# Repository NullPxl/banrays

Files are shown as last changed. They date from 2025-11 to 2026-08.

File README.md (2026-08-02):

# Ban-Rays
**Glasses to detect smart-glasses that have cameras**

I'm experimenting with 2 main approaches:
* [Optics](#optics): classify the camera using light reflections.
* [Networking](#networking): bluetooth and wi-fi analysis.

So far fingerprinting specific devices based on bluetooth (BLE) is looking like easiest and most reliable approach. The picture below is the first version, which plays the legend of zelda 'secret found' jingle when it detects a BLE advertisement from Meta Raybans.

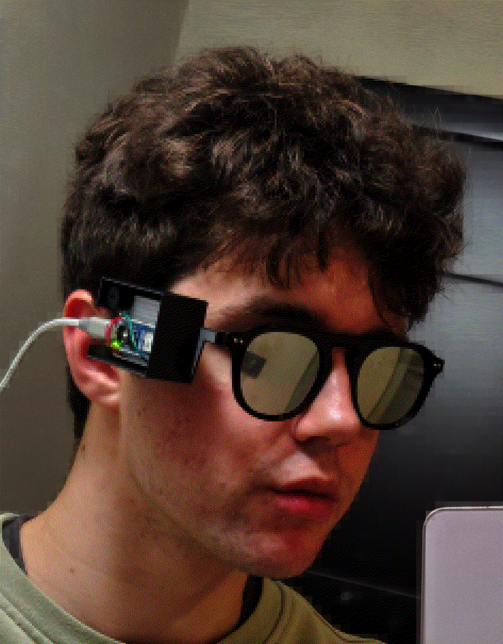
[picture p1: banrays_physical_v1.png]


I'm essentially treating this README like a logbook, so it will have my current approaches/ideas.

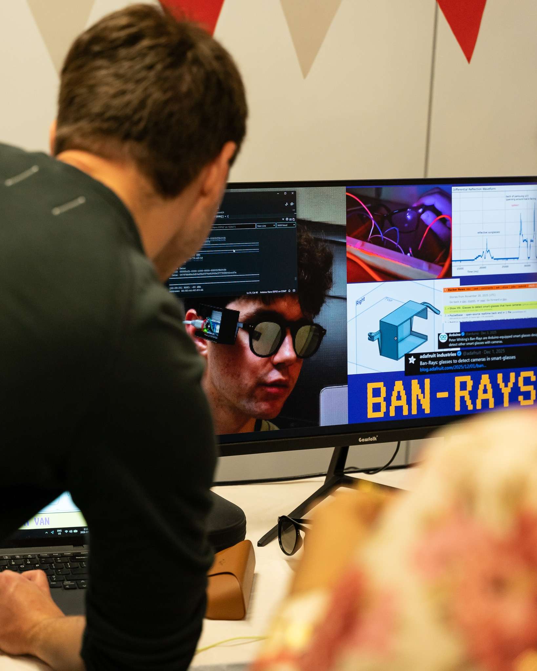
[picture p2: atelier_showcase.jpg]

Back when I released this initial research around November 2025 it hit top of hackernews and got some nice tweets! I also got to show it to some cool people at Atelier Showcase.

## Optics

By sending IR at camera lenses, we can take advantage of the fact that the CMOS sensor in a camera reflects light directly back at the source (called 'retro-reflectivity' / 'cat-eye effect') to identify cameras.

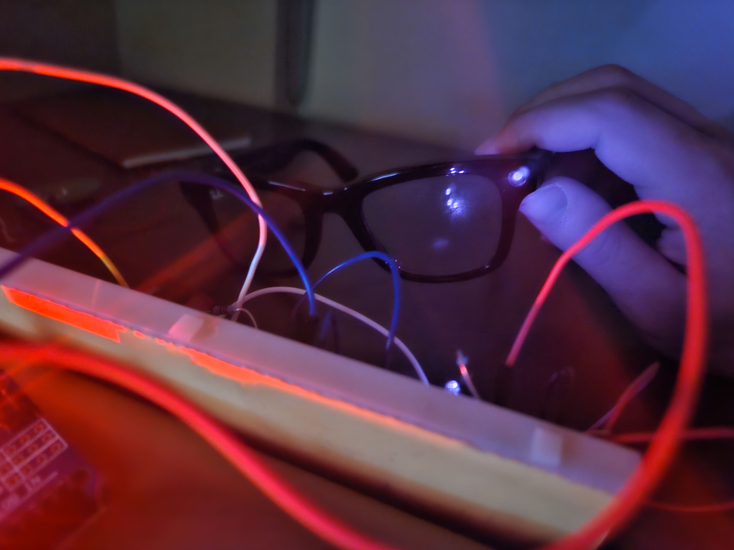
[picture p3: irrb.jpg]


This isn't exactly a new idea. Some researchers in 2005 used this property to create 'capture-resistant environments' when smartphones with cameras were gaining popularity. 
* https://homes.cs.washington.edu/~shwetak/papers/cre.pdf

There's even some recent research (2024) that figured out how to classify individual cameras based on their retro-reflections.
* https://opg.optica.org/oe/fulltext.cfm?uri=oe-32-8-13836

Now we have a similar situation to those 2005 researchers on our hands, where smart glasses with hidden cameras seem to be getting more popular. So I want to create a pair of glasses to identify these. Unfortunately, from what I can tell most of the existing research in this space records data with a camera and then uses ML, a ton of controlled angles, etc. to differentiate between normal reflective surfaces and cameras. 

I would feel pretty silly if my solution uses its own camera. So I'll be avoiding that. Instead I think it's likely I'll have to rely on being consistent with my 'sweeps', and creating a good classifier based on signal data. For example you can see here that the back camera on my smartphone seems to produce quick and large spikes, while the glossy screen creates a more prolonged wave. 

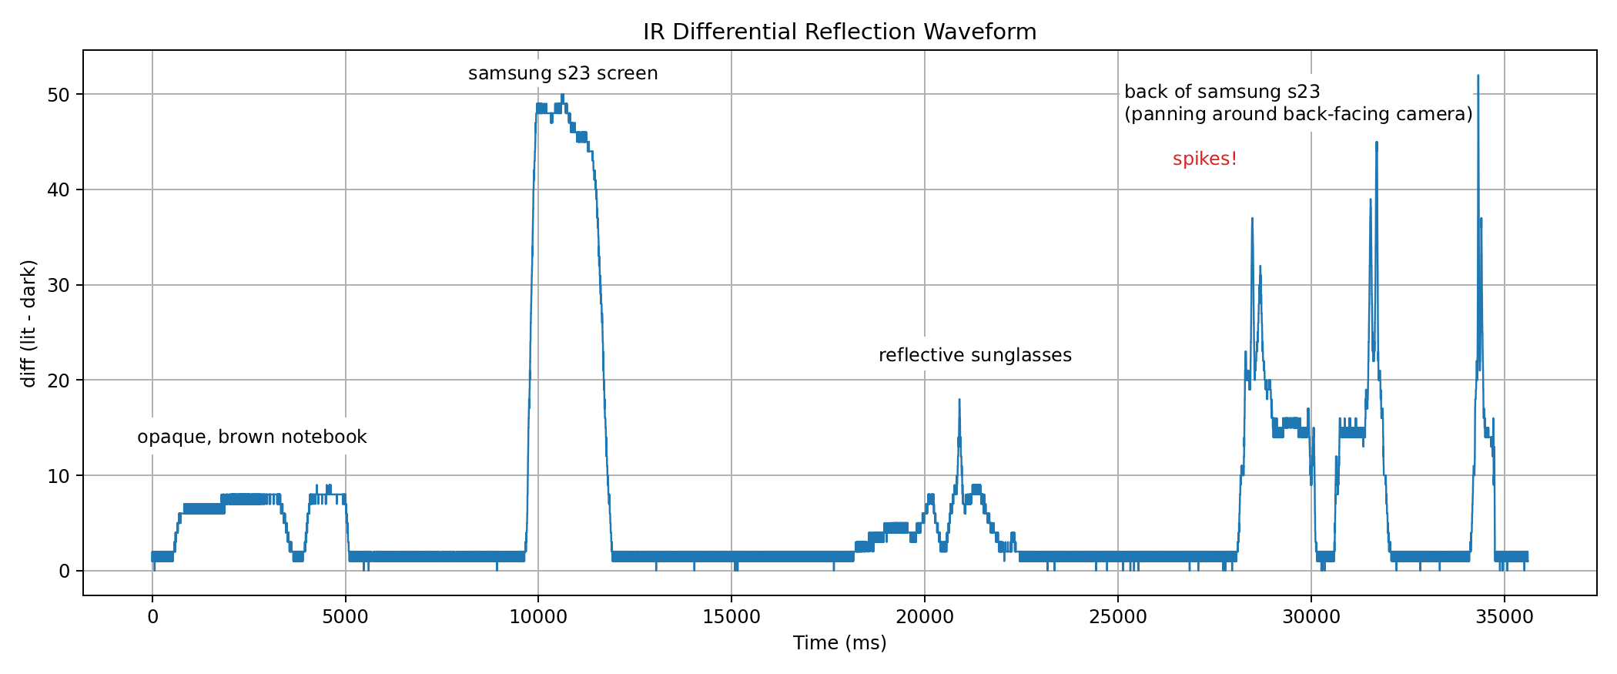
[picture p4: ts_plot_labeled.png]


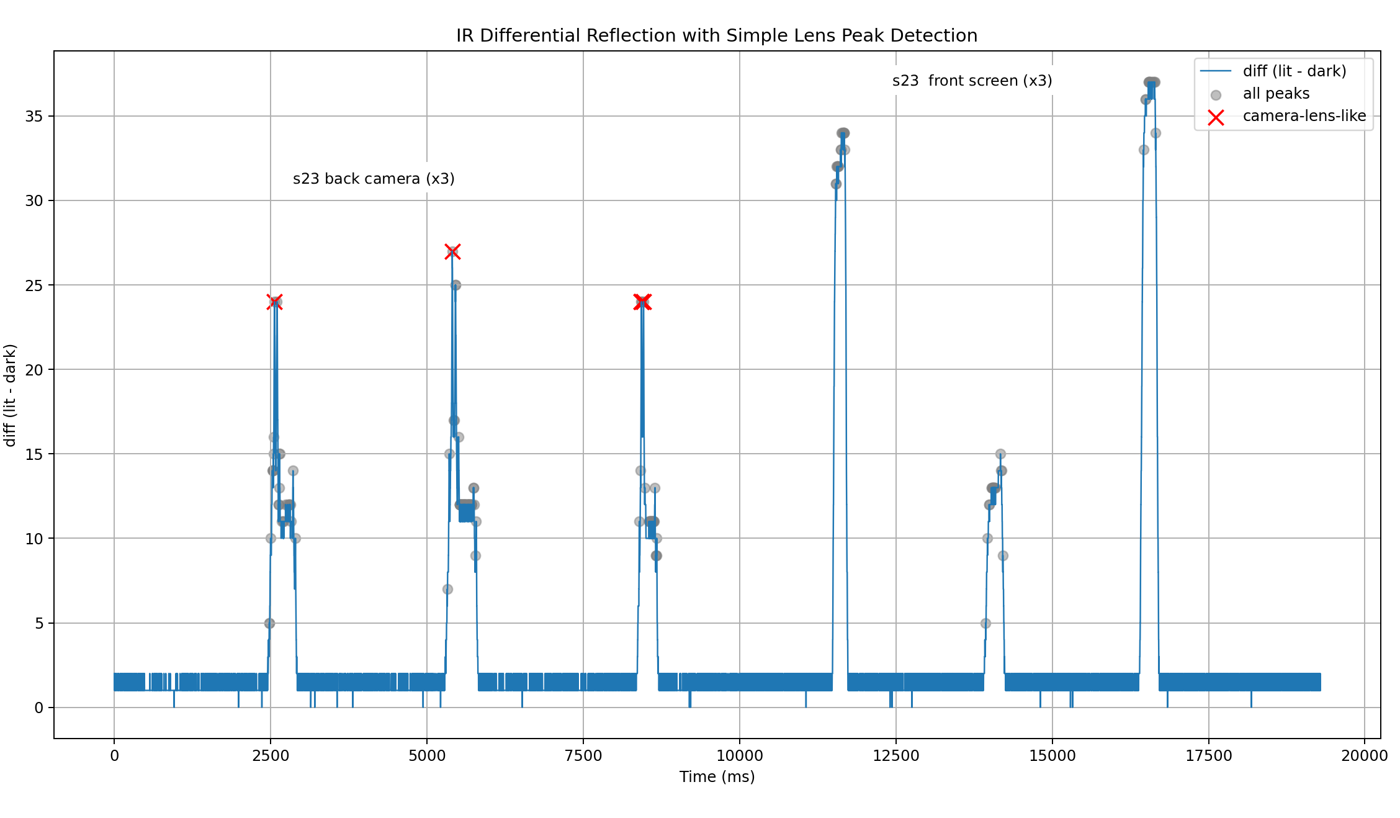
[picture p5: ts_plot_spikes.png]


After getting to test some Meta Raybans, I found that this setup is not going to be sufficient. Here's a test of some sweeps of the camera-area + the same area when the lens is covered. You can see the waveform is similar to what I saw in the earlier test (short spike for camera, wider otherwise), but it's wildly inconsistent and the strength of the signal is very weak. This was from about 4 inches away from the LEDs. I didn't notice much difference when swapping between 940nm and 850nm LEDs.

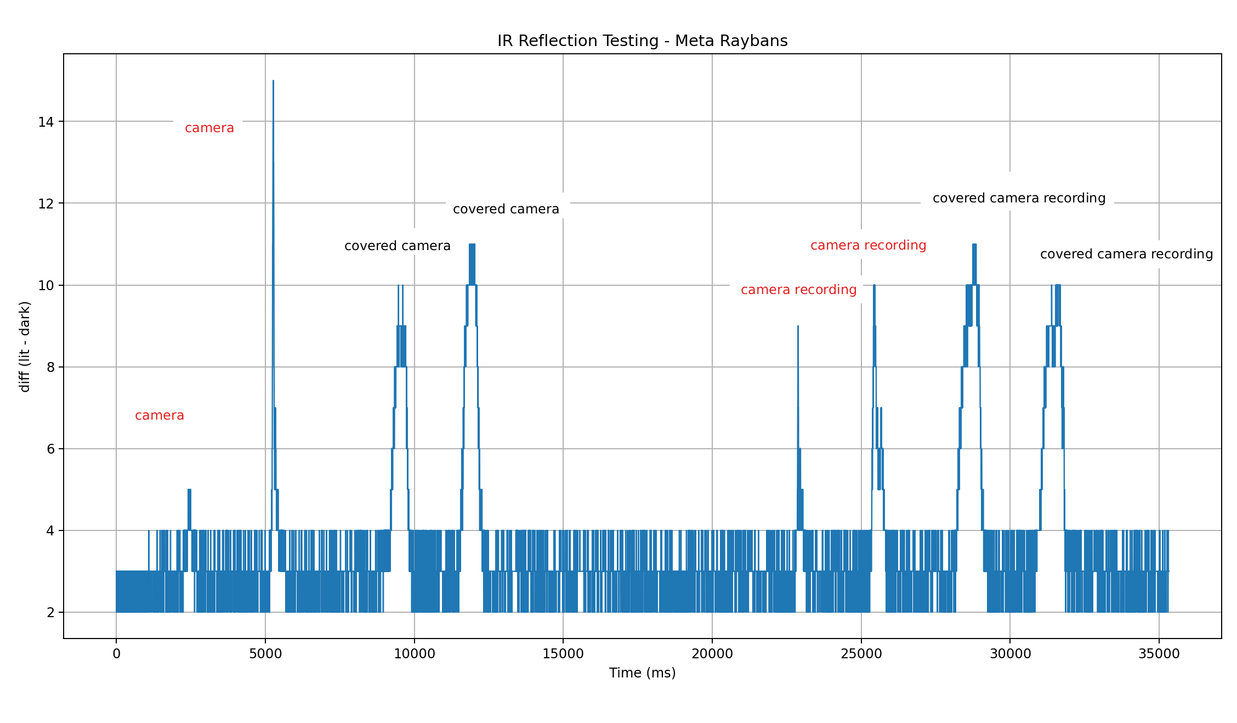
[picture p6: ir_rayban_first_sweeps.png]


So at least with current hardware that's easy for me to access, this probably isn't enough to differentiate accurately.

Another idea I had is to create a designated sweep 'pattern'. The user (wearing the detector glasses) would perform a specific scan pattern of the target. Using the waveforms captured from this data, maybe we can more accurately fingerprint the raybans. For example, sweeping across the targets glasses in a 'left, right, up, down' approach. I tested this by comparing the results of the Meta raybans vs some aviators I had lying around. I think the idea behind this approach is sound (actually it's light), but it might need more workshopping.

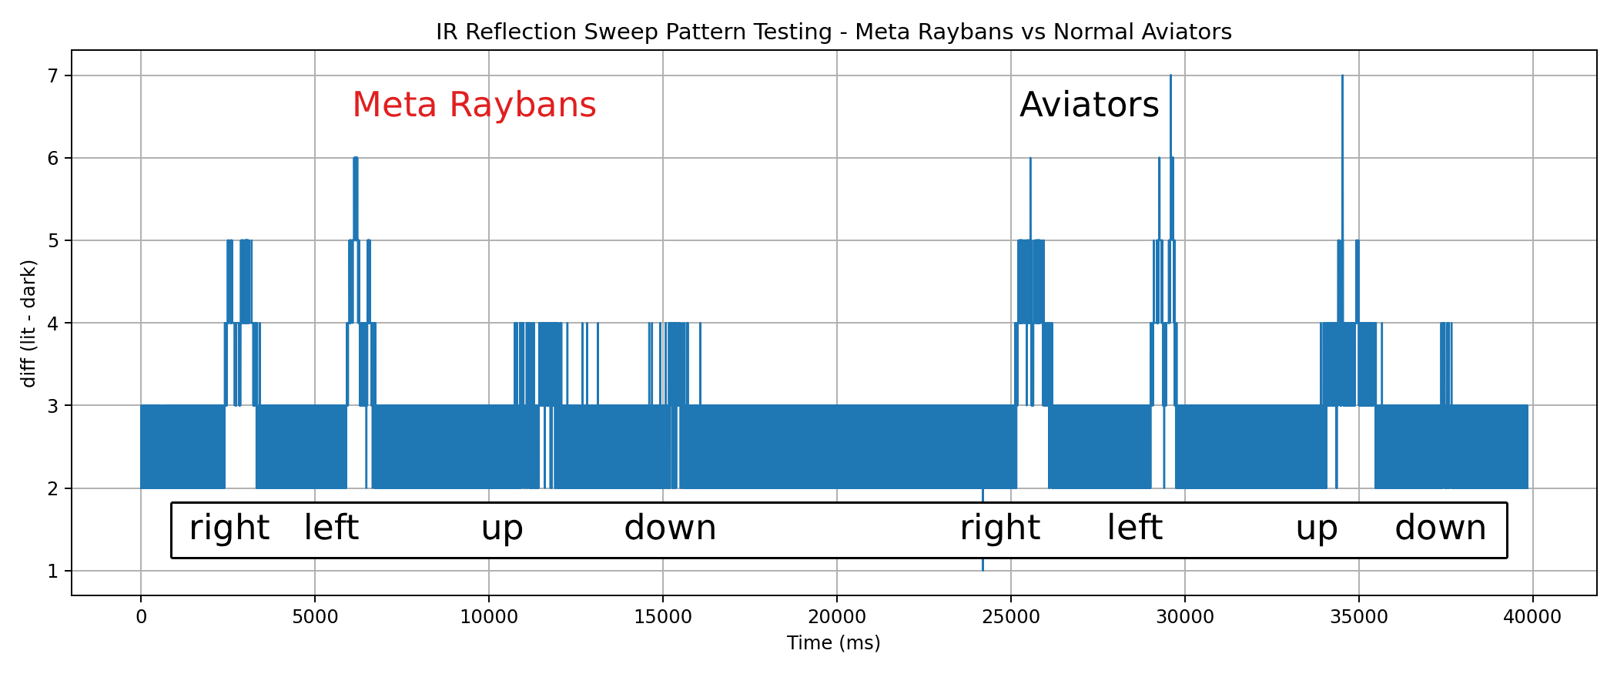
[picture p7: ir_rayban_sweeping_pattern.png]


### IR Circuit

For prototyping, I'm using:
* Arduino uno
* a bunch of 940nm and 850nm IR LEDs
* a photodiode as a receiver
* a 2222A transistor

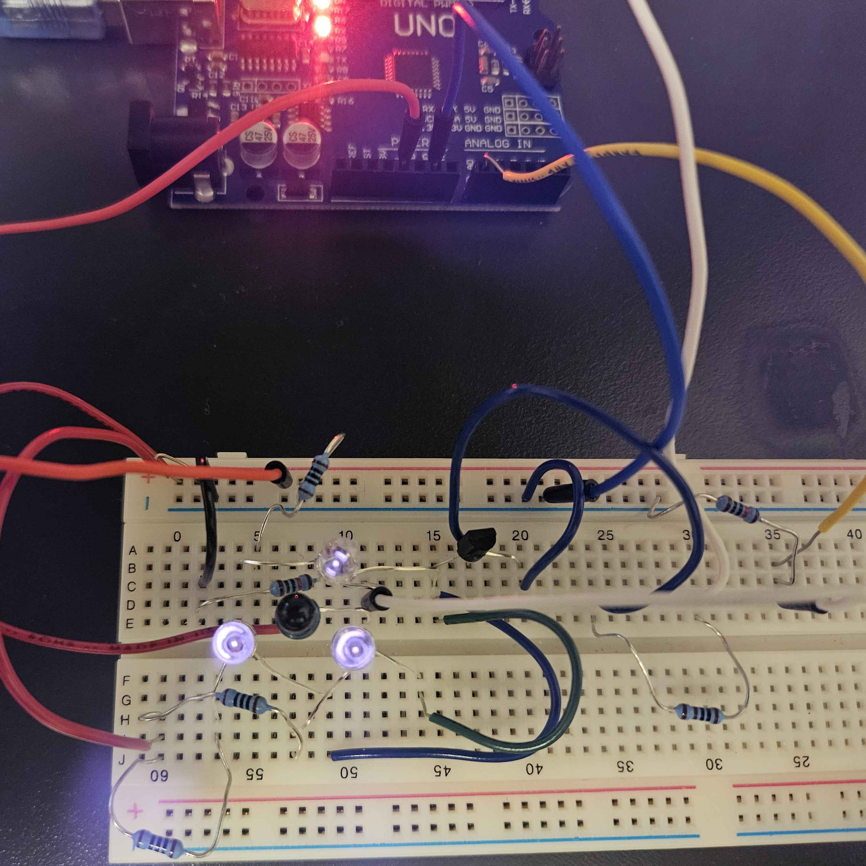
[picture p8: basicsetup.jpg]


IR TODOs:
* experiment with sweeping patterns
* focus on spectral info, try combining data from a few different wavelengths
* collimation?

* trevor (author of the camera classification paper) mentioned back in november that if the glasses have LiDAR i could just look for those pulses. the ray-bans don't seem to have this, but other smart glasses might. this blog posted in december has some cool research on detecting iphone cameras with this approach: https://www.atredis.com/blog/2025/11/20/designing-a-passive-lidar-detection-sensor

## Networking

This has been more tricky than I first thought! My current approach here is to fingerprint the Meta Raybans over Bluetooth low-energy (BLE) advertisements. But, **I have only been able to detect BLE traffic during 1) pairing 2) powering-on**. I sometimes also see the advertisement as they are taken out of the case (while already powered on), but not consistently. 

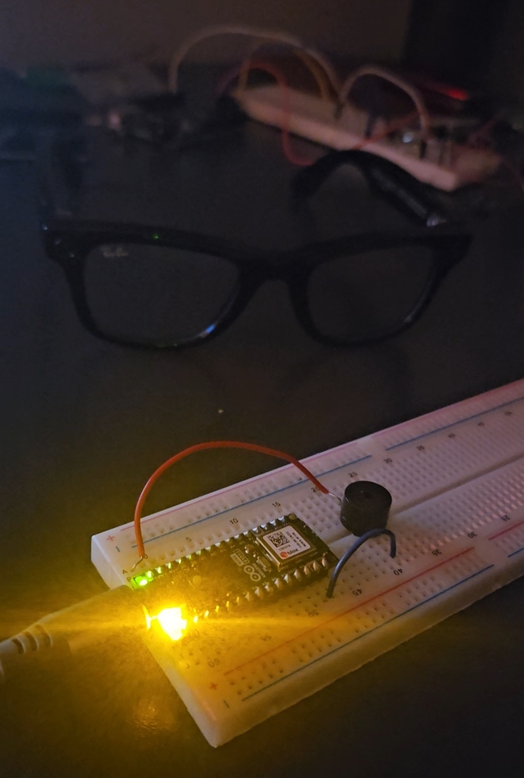
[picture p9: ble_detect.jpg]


The goal is to detect them during usage when they're communicating with the paired phone, but to see this type of directed BLE traffic I would first need to see the `CONNECT_REQ` packet which has information as to what which of the communication channels to hop between in sync (hop interval, hop increment). This can be done with an [nRF52840 + the ble-sniffer firmware](https://academy.nordicsemi.com/courses/bluetooth-low-energy-fundamentals/lessons/lesson-6-bluetooth-le-sniffer/topic/nrf-sniffer-for-bluetooth-le/), but it doesn't negate the fact that **you still need to see that initial connection to start sniffing**. 

A bit more background on BLE:
* operates over 40 channels, 3 of which are dedicated just for advertising while the others are for actual data. 
* modern devices (like the meta ray-bans) have randomized public MAC addresses for privacy. Even though IEEE assigns certain MAC address prefixes (OUI, 'Organizationally Unique Identifier'), the randomization means this doesn't appear to be useful for detection. 
* to follow a conversation on the data channels, you need to have observed the initial connection request packet with has required info in it
* the advertising data contains good stuff, but isn't necessarily sent out super often. when extended advertising is used to get a bigger payload size, the other channels can be used for it. 
* https://academy.nordicsemi.com/courses/bluetooth-low-energy-fundamentals/lessons/lesson-2-bluetooth-le-advertising/topic/advertisement-packet/
* you can send a SCAN_REQ to devices that are advertising and they (can choose to) respond with more data about themselves ('active scanning')

When turned on or put into pairing mode (or sometimes when taken out of the case), I can detect the device through advertised manufacturer data and service UUIDs. These are parts of the advertising data.
`0x01AB` is a Meta-specific SIG-assigned ID (assigned by the Bluetooth standards body), and `0xFD5F` in the Service UUID is assigned to Meta as well. In the code you can see the other numbers I'm using for fingerprinting.
* https://www.bluetooth.com/wp-content/uploads/Files/Specification/HTML/Assigned_Numbers/out/en/Assigned_Numbers.pdf

For any of the bluetooth classic (BTC) traffic, unfortunately the hardware seems a bit more involved (read: expensive). So if I want to do down this route, I'll likely need a more clever solution here.

capture when the glasses are powered on:
```
[01:07:06] RSSI: -59 dBm
Address: XX:XX:XX:XX:XX:XX
Name: Unknown

META/LUXOTTICA DEVICE DETECTED!
  Manufacturer: Meta (0x01AB)
  Service UUID: Meta (0xFD5F) (0000fd5f-0000-1000-8000-00805f9b34fb)

Manufacturer Data:
  Company ID: Meta (0x01AB)
  Data: 020102102716e4

Service UUIDs: ['0000fd5f-0000-1000-8000-00805f9b34fb']
```

NETWORKING TODOs:
* Read: https://dl.acm.org/doi/10.1145/3548606.3559372 and any other recent papers 
* Wi-Fi direct stuff with esp32
* see if the nrf52840 sees anything on adv that the esp32 doesn't. 
  * I bought the chip (xiao nrf52840) to test out sniffing, but I should've just got the dongle or a dev-kit. the nordic ble-sniffer firmware isn't made for it so it's taking some more effort.
* will phones advertise more often and show specific services? anything the phone might do differently when paired to an active device that i can use as a side channel?
* read more into the PHY modes

---

NOTE: ray-bans that i was using for testing are currently unavailable so i'm a bit blocked :(

---

Thanks to Trevor Seets and Junming Chen for their advice in optics and BLE (respectively). Also to Sohail for lending me meta raybans to test with. 

---

[][cc-by-nc-sa]

This work is licensed under a
[Creative Commons Attribution-NonCommercial-ShareAlike 4.0 International License][cc-by-nc-sa].

[][cc-by-nc-sa]

[cc-by-nc-sa]: http://creativecommons.org/licenses/by-nc-sa/4.0/
[cc-by-nc-sa-image]: https://licensebuttons.net/l/by-nc-sa/4.0/88x31.png
[cc-by-nc-sa-shield]: https://img.shields.io/badge/License-CC%20BY--NC--SA%204.0-lightgrey.svg

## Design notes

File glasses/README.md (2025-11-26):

## stuff for the actual glasses

1. detect presense of meta raybans / other camera glasses
2. alert wearer (currently plays the legend of zelda secret found jingle)
3. potentially turn on a ton of IR-leds to make the wearer difficult to identify through a camera

For mechanical side, i bought a $1 pair of sunglasses, unscrewed one of the hinges, re-created it with CAD, and modified it a bit so there's a spot to hold electronics.

`arm_and_box.step`
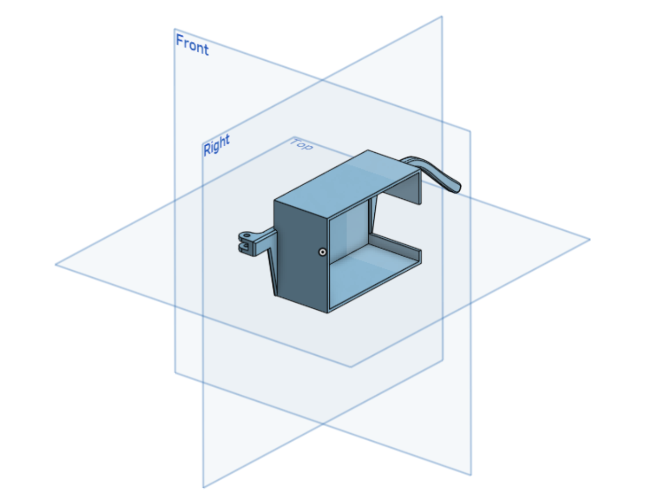
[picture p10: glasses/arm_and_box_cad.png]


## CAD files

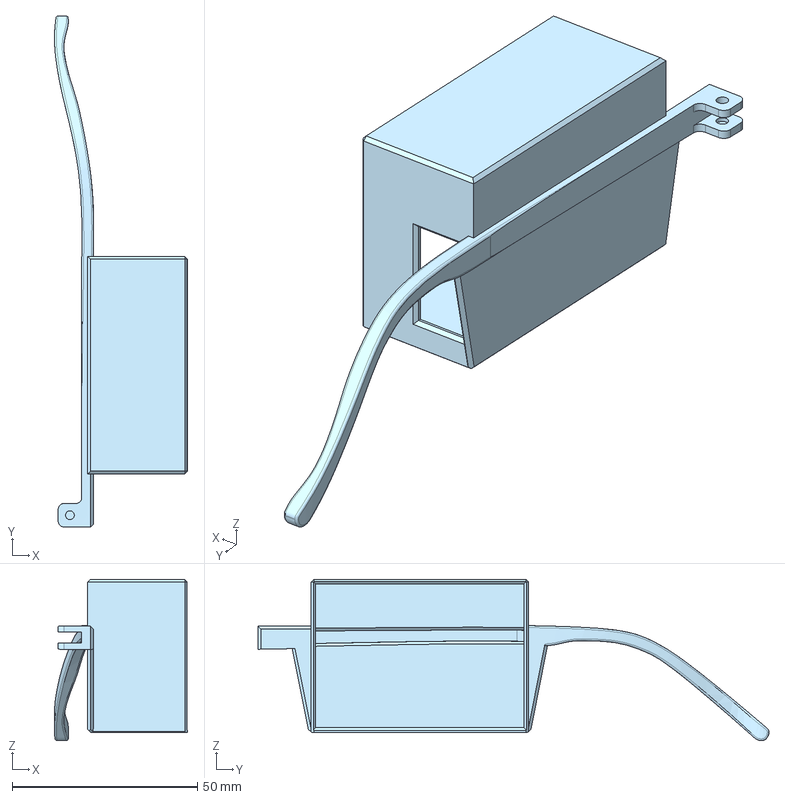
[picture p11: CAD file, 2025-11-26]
glasses/arm_and_box.step
35.9 x 137.9 x 43.5 mm

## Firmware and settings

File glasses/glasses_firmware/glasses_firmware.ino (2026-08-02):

#include <BLEDevice.h>
#include <BLEUtils.h>
#include <BLEScan.h>
#include <BLEAdvertisedDevice.h>

#include "zelda_secret.h"

// ========== CONFIGURATION ==========
const int RSSI_THRESHOLD = -150;        // Only show devices stronger than this
const int DETECTION_PIN = 13;
const int SCAN_TIME = 5;               // Scan duration in seconds

unsigned long lastSoundTime = 0;
const unsigned long SOUND_COOLDOWN = 30000;  // 30 seconds in milliseconds

// Meta and Luxottica company identifiers
const uint16_t META_IDENTIFIERS[] = {
  0xFD5F,  // Meta (0xFD5F)
  0xFEB7,  // Meta (0xFEB7)
  0xFEB8,  // Meta (0xFEB8)
  0x01AB,  // Meta (0x01AB)
  0x058E,  // Meta (0x058E)
  0x0D53,   // Luxottica (0x0D53)

  0xFEF3 // my phone (for testing to trigger)
};
const int META_ID_COUNT = 7;

// MAC addresses are randomized, so not checking OUI here (maybe do it for BTC)
    // mac.rfind("48:05:60", 0) == 0 ||
    // mac.rfind("CC:A1:74", 0) == 0 ||
    // mac.rfind("C0:DD:8A", 0) == 0 ||
    // mac.rfind("D0:B3:C2", 0) == 0 ||
    // mac.rfind("88:25:08", 0) == 0 ||
    // mac.rfind("94:F9:29", 0) == 0 ||
    // mac.rfind("D4:D6:59", 0) == 0 ||
    // mac.rfind("78:C4:FA", 0) == 0 ||
    // mac.rfind("B4:17:A8", 0) == 0 ||
    // mac.rfind("50:99:03", 0) == 0 ||
    // mac.rfind("80:F3:EF", 0) == 0 ||
    // mac.rfind("84:57:F7", 0) == 0 ||
    // mac.rfind("3C:28:6D", 0) == 0 ||
    // mac.rfind("AC:37:43", 0) == 0 ||
    // // Luxottica
    // mac.rfind("98:59:49", 0) == 0

// Identifiers to filter out (from local test setup)
const uint16_t BLOCKED_IDENTIFIERS[] = {
  0xFD5A,  // Samsung
  0xFD69,   // Samsung
  0x004C, //apple
  0x0006, // microsoft
  // 0xFEF3, // phone
};
const int BLOCKED_ID_COUNT = 4;

// ========== GLOBALS ==========
BLEScan* pBLEScan;
unsigned long sessionStartTime = 0;

// ========== DETECTION RESULT STRUCT ==========
struct DetectionResult {
  bool isBlocked;
  bool isMetaDevice;
  String matches[10];  // Store up to 10 match descriptions
  int matchCount;
};

// ========== HELPER FUNCTIONS ==========

String getCompanyName(uint16_t companyId) {
  switch(companyId) {
    case 0xFD5F: return "Meta (0xFD5F)";
    case 0xFEB7: return "Meta (0xFEB7)";
    case 0xFEB8: return "Meta (0xFEB8)";
    case 0x01AB: return "Meta (0x01AB)";
    case 0x058E: return "Meta (0x058E)";
    case 0x0D53: return "Luxottica (0x0D53)";
    default: {
      char buf[32];
      sprintf(buf, "Unknown (0x%04X)", companyId);
      return String(buf);
    }
  }
}

bool isMetaIdentifier(uint16_t id) {
  for(int i = 0; i < META_ID_COUNT; i++) {
    if(META_IDENTIFIERS[i] == id) return true;
  }
  return false;
}

bool isBlockedIdentifier(uint16_t id) {
  for(int i = 0; i < BLOCKED_ID_COUNT; i++) {
    if(BLOCKED_IDENTIFIERS[i] == id) return true;
  }
  return false;
}

String formatTimestamp() {
  unsigned long ms = millis() - sessionStartTime;
  unsigned long seconds = ms / 1000;
  unsigned long minutes = seconds / 60;
  unsigned long hours = minutes / 60;
  
  char buf[16];
  sprintf(buf, "%02lu:%02lu:%02lu", hours % 24, minutes % 60, seconds % 60);
  return String(buf);
}

String hexString(uint8_t* data, size_t len) {
  String result = "";
  for(size_t i = 0; i < len; i++) {
    char buf[4];
    sprintf(buf, "%02x", data[i]);
    result += buf;
  }
  return result;
}

// Extract 16-bit identifier from 128-bit UUID (format: 0000XXXX-0000-1000-8000-00805f9b34fb)
uint16_t extract16BitFromUUID(String uuid) {
  if(uuid.length() == 36) {
    // Extract characters at positions 4-7 (the XXXX part)
    String hex = uuid.substring(4, 8);
    return (uint16_t)strtol(hex.c_str(), NULL, 16);
  }
  return 0;
}

// ========== DETECTION LOGIC ==========

DetectionResult checkDevice(BLEAdvertisedDevice& device) {
  DetectionResult result = {false, false, {}, 0};
  
  // Check manufacturer data
  if(device.haveManufacturerData()) {
    std::string mfgData = device.getManufacturerData();
    if(mfgData.length() >= 2) {
      // Little-endian: first byte is LSB, second is MSB
      uint16_t companyId = ((uint8_t)mfgData[1] << 8) | (uint8_t)mfgData[0];
      
      if(isBlockedIdentifier(companyId)) {
        result.isBlocked = true;
        return result;
      }
      
      if(isMetaIdentifier(companyId)) {
        result.isMetaDevice = true;
        result.matches[result.matchCount++] = "Manufacturer: " + getCompanyName(companyId);
      }
    }
  }
  
  // Check service UUIDs (loop through all)
  if(device.haveServiceUUID()) {
    for(int i = 0; i < device.getServiceUUIDCount(); i++) {
      BLEUUID serviceUUID = device.getServiceUUID(i);
      String uuidStr = String(serviceUUID.toString().c_str());
      uuidStr.toLowerCase();
      
      uint16_t identifier = extract16BitFromUUID(uuidStr);
      if(identifier != 0) {
        if(isBlockedIdentifier(identifier)) {
          result.isBlocked = true;
          return result;
        }
        
        if(isMetaIdentifier(identifier)) {
          result.isMetaDevice = true;
          result.matches[result.matchCount++] = "Service UUID: " + getCompanyName(identifier) + " (" + uuidStr + ")";
        }
      }
    }
  }

  // Check service data UUID
  if(device.haveServiceData()) {
    BLEUUID svcDataUUID = device.getServiceDataUUID();
    String uuidStr = String(svcDataUUID.toString().c_str());
    uuidStr.toLowerCase();
    
    uint16_t identifier = extract16BitFromUUID(uuidStr);
    if(identifier != 0) {
      if(isBlockedIdentifier(identifier)) {
        result.isBlocked = true;
        return result;
      }
      
      if(isMetaIdentifier(identifier)) {
        result.isMetaDevice = true;
        result.matches[result.matchCount++] = "Service Data UUID: " + getCompanyName(identifier) + " (" + uuidStr + ")";
      }
    }
  }
  
  return result;
}

// ========== BLE CALLBACK ==========

class MetaDetectionCallbacks : public BLEAdvertisedDeviceCallbacks {
  void onResult(BLEAdvertisedDevice device) {
    // Filter by RSSI
    if(device.getRSSI() < RSSI_THRESHOLD) return;
    
    // Check for Meta/Luxottica identifiers
    DetectionResult detection = checkDevice(device);
    
    // Skip blocked devices
    if(detection.isBlocked) return;
    
    // Build output
    String output = "\n";
    output += "======================================================================\n";
    output += "[" + formatTimestamp() + "] RSSI: " + String(device.getRSSI()) + " dBm\n";
    output += "Address: " + String(device.getAddress().toString().c_str()) + "\n";
    output += "Name: " + String(device.haveName() ? device.getName().c_str() : "Unknown") + "\n";
    
    // Highlight Meta/Luxottica devices
    if(detection.isMetaDevice) {
      output += "\n🔍 META/LUXOTTICA DEVICE DETECTED!\n";
      for(int i = 0; i < detection.matchCount; i++) {
        output += "  ✓ " + detection.matches[i] + "\n";
      }
      
      // alert user
      
      digitalWrite(DETECTION_PIN, HIGH);
      // play sound only if cooldown has elapsed
      unsigned long currentTime = millis();
      if (lastSoundTime == 0 || currentTime - lastSoundTime >= SOUND_COOLDOWN) {
        zeldaSecret();
        lastSoundTime = currentTime;
        output += "  🔊 Playing alert sound\n";
      } else {
        unsigned long remaining = (SOUND_COOLDOWN - (currentTime - lastSoundTime)) / 1000;
        output += "  🔇 Sound on cooldown (" + String(remaining) + "s remaining)\n";
      }

    }
    
    // Print manufacturer data
    if(device.haveManufacturerData()) {
      std::string mfgData = device.getManufacturerData();
      output += "\nManufacturer Data:\n";
      
      if(mfgData.length() >= 2) {
        uint16_t companyId = ((uint8_t)mfgData[1] << 8) | (uint8_t)mfgData[0];
        output += "  Company ID: " + getCompanyName(companyId) + "\n";
      }
      
      output += "  Data: " + hexString((uint8_t*)mfgData.c_str(), mfgData.length()) + "\n";
    }
    
    // Print service UUIDs
    if(device.haveServiceUUID()) {
      output += "\nService UUIDs: [";
      for(int i = 0; i < device.getServiceUUIDCount(); i++) {
        BLEUUID serviceUUID = device.getServiceUUID(i);
        output += "'" + String(serviceUUID.toString().c_str()) + "'";
        if(i < device.getServiceUUIDCount() - 1) {
          output += ", ";
        }
      }
      output += "]\n";
    }
    
    // Print service data if available
    if(device.haveServiceData()) {
      std::string svcData = device.getServiceData();
      BLEUUID svcUUID = device.getServiceDataUUID();
      output += "\nService Data:\n";
      output += "  UUID: " + String(svcUUID.toString().c_str()) + "\n";
      output += "  Data: " + hexString((uint8_t*)svcData.c_str(), svcData.length()) + "\n";
    }
    
    // Print local name if different from advertised name
    if(device.haveName()) {
      output += "\nLocal Name: " + String(device.getName().c_str()) + "\n";
    }
    
    output += "======================================================================\n";
    
    Serial.print(output);
  }
};

MetaDetectionCallbacks callbacks;

// ========== SETUP ==========

void setup() {
  Serial.begin(115200);
  setupZeldaSound();   // initialize LEDC for buzzer

  delay(1000);
  
  // Configure detection pin
  pinMode(DETECTION_PIN, OUTPUT);
  digitalWrite(DETECTION_PIN, LOW);
  
  sessionStartTime = millis();
  
  Serial.println("\n======================================================================");
  Serial.println("BLE Scanner - Detecting Meta Ray-Ban Smart Glasses");
  Serial.println("======================================================================");
  Serial.print("RSSI Threshold: ");
  Serial.print(RSSI_THRESHOLD);
  Serial.println(" dBm (showing devices stronger than this)");
  
  Serial.print("Monitoring for Meta identifiers: ");
  for(int i = 0; i < META_ID_COUNT; i++) {
    Serial.printf("0x%04X", META_IDENTIFIERS[i]);
    if(i < META_ID_COUNT - 1) Serial.print(", ");
  }
  Serial.println();
  
  Serial.print("Blocking: ");
  for(int i = 0; i < BLOCKED_ID_COUNT; i++) {
    Serial.printf("0x%04X", BLOCKED_IDENTIFIERS[i]);
    if(i < BLOCKED_ID_COUNT - 1) Serial.print(", ");
  }
  Serial.println(" (Samsung)");
  
  Serial.print("Detection Pin: GPIO ");
  Serial.println(DETECTION_PIN);
  
  Serial.println("\n======================================================================");
  Serial.print("NEW SCAN SESSION - ");
  Serial.println(formatTimestamp());
  Serial.println("======================================================================");
  Serial.println("\nScanning...\n");
  
  // Initialize BLE
  BLEDevice::init("");
  pBLEScan = BLEDevice::getScan();
  pBLEScan->setAdvertisedDeviceCallbacks(&callbacks, true);
  pBLEScan->setActiveScan(true);
  pBLEScan->setInterval(100);
  pBLEScan->setWindow(99);
}

// ========== LOOP ==========

void loop() {
  // Reset detection pin at start of each scan
  digitalWrite(DETECTION_PIN, LOW);
  
  // Scan for devices
  BLEScanResults foundDevices = pBLEScan->start(SCAN_TIME, false);
  pBLEScan->clearResults();
  
  delay(50);
}

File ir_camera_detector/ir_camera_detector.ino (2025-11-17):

// pins
const int ledPin    = 3;   // drives 2N2222A base
const int sensorPin = A0;  // IR photodiode junction
const int detectLed = 13;  // onboard LED indicator

// tunables
int pulseDelay = 200;      // microseconds: ON/OFF IR settle time
int threshold  = 30;       // diff needed to count as "detected"


unsigned long startTime;

void setup() {
  pinMode(ledPin, OUTPUT);
  pinMode(detectLed, OUTPUT);
  Serial.begin(115200);

  startTime = millis();
  Serial.println("ms,diff"); // csv header
}

int readDiff() {
  // LED OFF (ambient only)
  digitalWrite(ledPin, LOW);
  delayMicroseconds(pulseDelay);
  int dark = analogRead(sensorPin);

  // LED ON (our IR + ambient)
  digitalWrite(ledPin, HIGH);
  delayMicroseconds(pulseDelay);
  int lit = analogRead(sensorPin);

  return (lit - dark);   // remove ambient
}

void loop() {
  int diff = readDiff();

  unsigned long t = millis() - startTime;

  Serial.print(t);
  Serial.print(",");
  Serial.println(diff);

  // simple threshold trigger
  if (diff > threshold) {
    digitalWrite(detectLed, HIGH);
  } else {
    digitalWrite(detectLed, LOW);
  }
}

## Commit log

2025-11-17 add spike things
    [ir_log_3camera_3screen.csv, ir_log_variousobjects.csv]
2025-11-17 add pic of circuit
    [detected_peaks_simple.csv]
2025-11-20 initial BLE tests + move around file/folder structure
    [detected_peaks_simple.csv, ir_log.csv, ir_log_3camera_3screen.csv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]
2025-11-22 add initial IR tests with raybans
    [detected_peaks_simple.csv, ir_log.csv, ir_log_0.csv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]
2025-11-26 add pictures and CAD file for v1 (just BLE broadcast detection)
    [arm_and_box.step]

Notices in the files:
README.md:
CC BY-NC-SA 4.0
